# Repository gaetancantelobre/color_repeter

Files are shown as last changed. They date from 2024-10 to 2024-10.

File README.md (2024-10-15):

Pi Pico (RP 2040) powered Simon Color game clone on a 41 mm coin footprint.
Code is free to use, modify,etc
Don't sell my design

Gerbers are available in the git.

Average cost per unit : 2.5 euros +- 0.2 euros.
Parts list :
 - pcb
 - 4x 6mm push button
 - 4x 1206 SMD LED
 - 5x 1206 220 Ohm Resistor
 - Pi Pico Zero (or clone, i use a aliexpress clone :)
 - 1x 5V piezo Buzzer

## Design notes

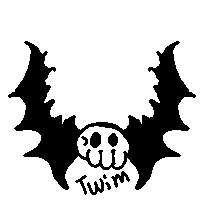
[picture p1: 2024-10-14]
pcb_art.png

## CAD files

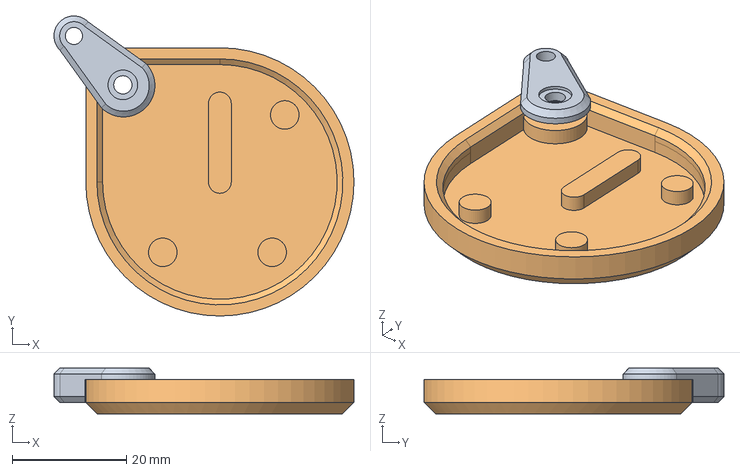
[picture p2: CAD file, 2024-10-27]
case.step
52.6 x 52.6 x 8.00 mm

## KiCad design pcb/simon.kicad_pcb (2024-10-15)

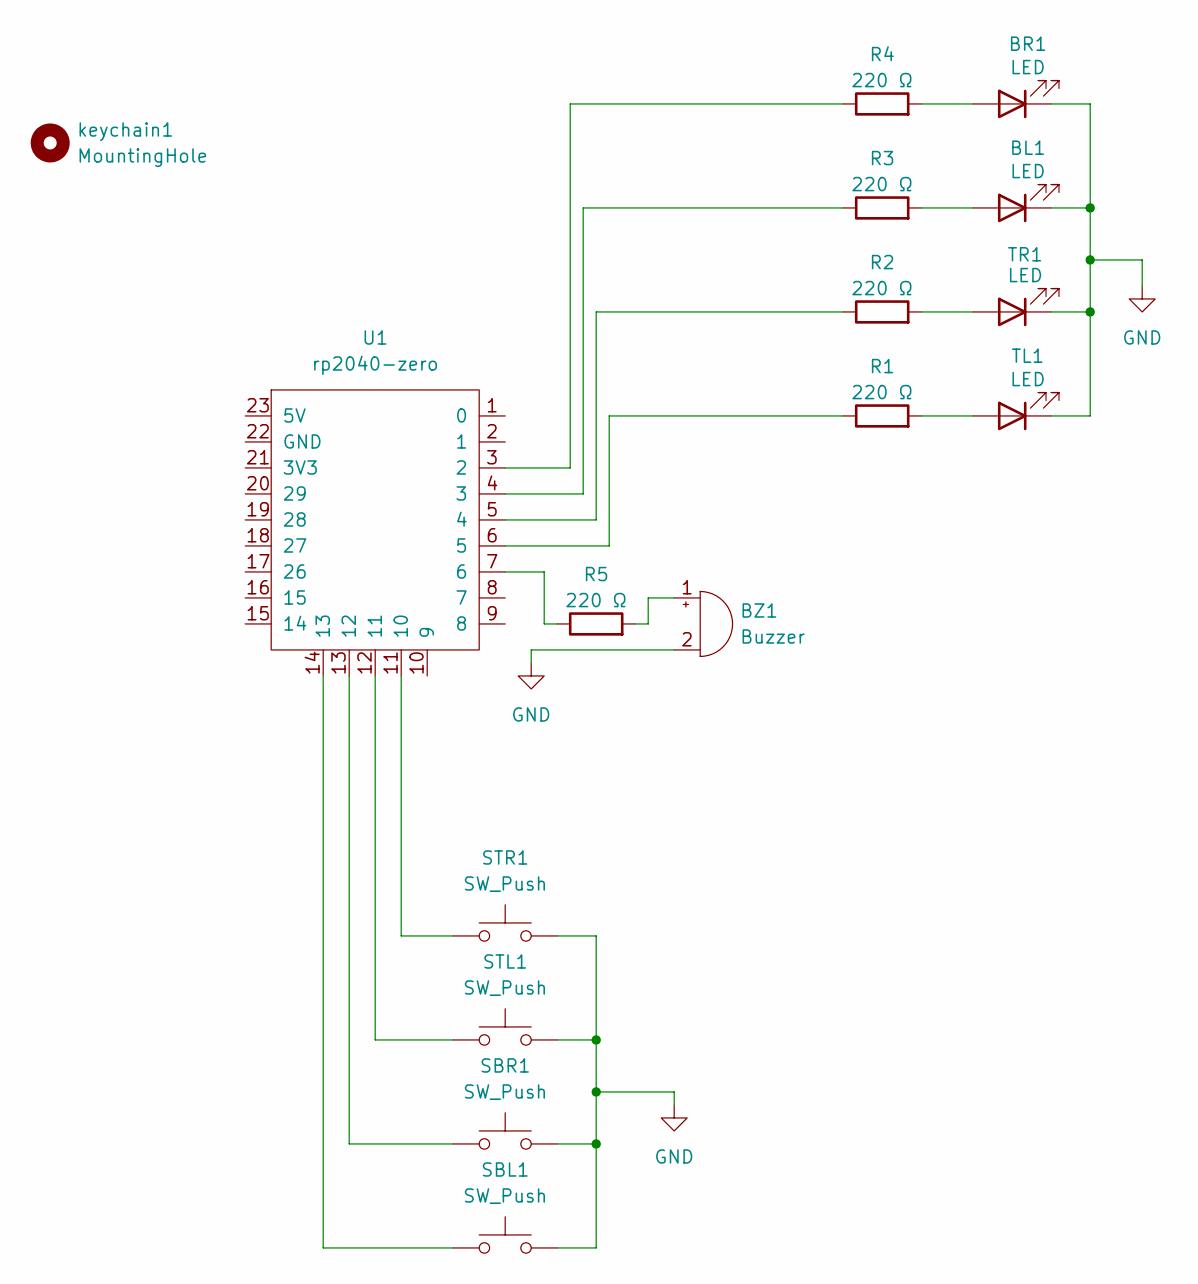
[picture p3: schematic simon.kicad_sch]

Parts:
BL1: LED; LED_1206_3216Metric_Pad1.42x1.75mm_HandSolder
BR1: LED; LED_1206_3216Metric_Pad1.42x1.75mm_HandSolder
BZ1: Buzzer; Buzzer_12x9.5RM7.6
R1, R2, R3, R4, R5: 220 Ω; R_1206_3216Metric_Pad1.30x1.75mm_HandSolder
SBL1: SW_Push; SW_PUSH_6mm
SBR1: SW_Push; SW_PUSH_6mm
STL1: SW_Push; SW_PUSH_6mm
STR1: SW_Push; SW_PUSH_6mm
TL1: LED; LED_1206_3216Metric_Pad1.42x1.75mm_HandSolder
TR1: LED; LED_1206_3216Metric_Pad1.42x1.75mm_HandSolder
U1: rp2040-zero; rp2040-zero-tht
keychain1: MountingHole; MountingHole_3.2mm_M3

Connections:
GND: BL1.1 (K), BR1.1 (K), BZ1.2 (-), SBL1.2, SBR1.2, STL1.2, STR1.2, TL1.1 (K), TR1.1 (K)
unnamed: BL1.2 (A), R3.2
unnamed: BR1.2 (A), R4.2
unnamed: BZ1.1 (+), R5.2
unnamed: R1.2, TL1.2 (A)
unnamed: R2.2, TR1.2 (A)
unnamed: R4.1, U1.3 (2)
unnamed: R3.1, U1.4 (3)
unnamed: R2.1, U1.5 (4)
unnamed: R1.1, U1.6 (5)
unnamed: R5.1, U1.7 (6)
unnamed: STR1.1, U1.11 (10)
unnamed: STL1.1, U1.12 (11)
unnamed: SBR1.1, U1.13 (12)
unnamed: SBL1.1, U1.14 (13)

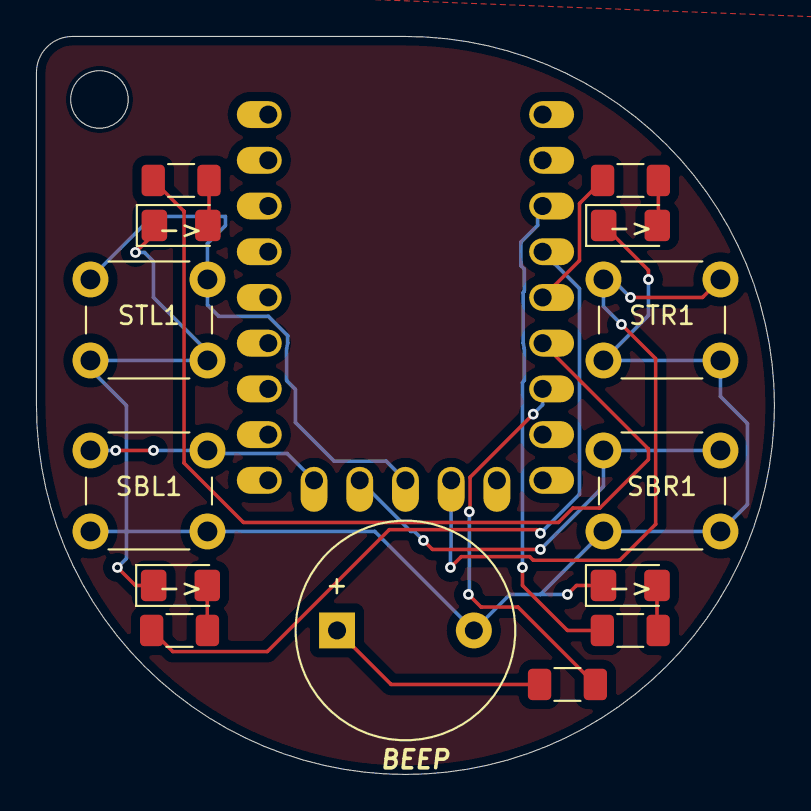
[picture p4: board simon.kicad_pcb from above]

Board: 2 copper layers, 41.0 x 41.0 mm, 16 parts (0 on the bottom side), 15 nets.

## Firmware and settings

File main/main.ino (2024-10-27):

int size = 100;
int current_move = 0;
int user_current_move = 0;
int* move_list;

unsigned long last_test = 0;
unsigned long min_delay = 240;

int buzzer = 6;
int inputs[4] = {0,0,0,0};
int lights[4] = {2,3,4,5};
int buttons[4] = {12,13,10,11};
int notes[4] = {55,110,220,440};
bool isWaiting = false;


int loser_song[5] = {55,65,233,20,333};

void generate_moves()
{
  for(int i = 0; i < size;i++)
  {
    move_list[i]= random(0, 4);
  }
}


void get_input()
{
  for(int i = 0; i < 4; i++)
  {
    inputs[i] = 0;
    if(digitalRead(buttons[i]) == 0)
    {
      inputs[i] = 1;
      
    }
  }
  
}

void play_move_to(int index)
{
  for(int i = 0; i < index;i++)
  {
    int color = move_list[i];

    for(int i = 0;i<4;i++)
    {
      digitalWrite(lights[i],0);
    }
    delay(150);

    digitalWrite(lights[color],1);
    tone(buzzer,notes[color]);
    delay(150);
    noTone(buzzer);
  }
}

void light_up_leds_input()
{
   for(int i = 0;i<4;i++)
  {
    digitalWrite(lights[i],0);
    noTone(buzzer);
  }
  for(int i = 0;i < 4;i++)
  {
    if(inputs[i])
    {
      digitalWrite(lights[i],1);
      tone(buzzer,notes[i]);
    }
  }
}

//TODO:
int check_move() //this is checking 24/7 make condition checking systeme if input is diff then 0,0,0,0
{
  unsigned long now = millis();
  unsigned long diff = now - last_test;
    for(int i = 0; i < 4;i++)
    {
      if(inputs[i] == 1)
      {
        if(diff > min_delay)
          {
            last_test = now;
            if(user_current_move < 100)
            {
              if(i == move_list[user_current_move])
              {
                return 1;
              }
              else
                return -1;
            }
              
          }
      }
    } 
    return 0;
}
  

void lose_animation()
{
  for(int j = 0;j < 5;j++)
  {
    for(int i = 0;i < 4;i++)
    {
      digitalWrite(lights[i],0);
    }
    delay(150);
    for(int i = 0;i < 4;i++)
    {
      digitalWrite(lights[i],1);
    }
    delay(150);
  }
}

void setup() {
  move_list = (int*)malloc(100 * sizeof(int));

  randomSeed(analogRead(0));
  generate_moves();
  for(int i = 0; i < 4;i++)
  {
    pinMode(lights[i],OUTPUT);
    pinMode(buttons[i],INPUT_PULLUP);
  }
  pinMode(buzzer,OUTPUT);
  Serial.begin(115200);
}

void reset()
{
  generate_moves();
  current_move = 0;
  user_current_move = 0;
  isWaiting = false;
}


void loop() {
  // put your main code here, to run repeatedly:
 
  if(!isWaiting)
  {
    current_move++;
    Serial.print("Current move :");
    Serial.println(current_move);
    play_move_to(current_move);
    isWaiting = true;
  }
  else
  {
    get_input();
    light_up_leds_input();
    int test = check_move();
    if(test == -1)
    {
      lose_animation();
      get_input();
      light_up_leds_input();
      reset();
      delay(2000);
    }
    else if(test)
    {
      user_current_move++;
      if(user_current_move >= current_move)
      {
        isWaiting = false;
        user_current_move = 0;
      }
    }
  }
}

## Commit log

2024-10-12 add pcb and code base
    [pcb.kicad_pcb, pcb.kicad_sch]
2024-10-14 added gerber files
    [pcb-B_Cu.gbr, pcb-B_Mask.gbr, pcb-B_Paste.gbr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]
2024-10-14 added basic game loop with out error treatement
    [main.ino]
2024-10-15 added full version
    [pcb.kicad_pcb]
2024-10-15 updated gerbers and transition to pi pico
    [pcb.kicad_sch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]
2024-10-27 cleaned repo and add .step files
    [case.step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]
2024-10-27 recleaned the git
    [simon.kicad_pcb, simon.kicad_sch]
